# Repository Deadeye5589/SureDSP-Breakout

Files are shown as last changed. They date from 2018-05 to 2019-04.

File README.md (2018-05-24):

# SureDSP-Breakout
Breakout Board for SureDSP to adapt China Modules

This project won't be supportet in any way, but on the other hand it can be used in any way you like.<br>
The creator of this project won't be responsible for any trouble, harm or deadly incidents that should occure while using this project data, parts of the project or complete boards.<br>
Now for the fun part.<br><br>

This breakout board includes an automotive qualified power supply with a quiescent current of >2µA. <br>
The DC/DC converter can supply the DSP down to an input voltage of 6V and is therefore suitable for start/stop systems.<br><br>

The modules can be purchased at the common Chinese webshops like Aliexpress<br><br>

The default configuration can support up to:<br>
4x DAC output via PCM5102 chipset 2,98€ per piece<br>
4x Analog output directly from SureDSP<br>
1x APTx Bluetooth receiver via CSR64215 chipset 8,08€<br>
1x SPDIF input via DIR9001 chipset 11,20€<br>
2x ADC input via PCM1808 Chipsatz 3,12€ per piece<br>
2x Analog Input from SureDSP<br>
1x Debugger 2,92€<br><br>

The PCB is the size of 160x100 mm and a 2 layer design.<br>
Drill holes are 0,8mm or 1,0mm<br>
The PCB can be etched with iron III chloride in a spray booth. <br>
It is possible to manufacture the PCB with tools avaiable to makers.<br>
But don't take on this project if you don't feel like you can do it by your own. <br>
You will not get any support.<br>

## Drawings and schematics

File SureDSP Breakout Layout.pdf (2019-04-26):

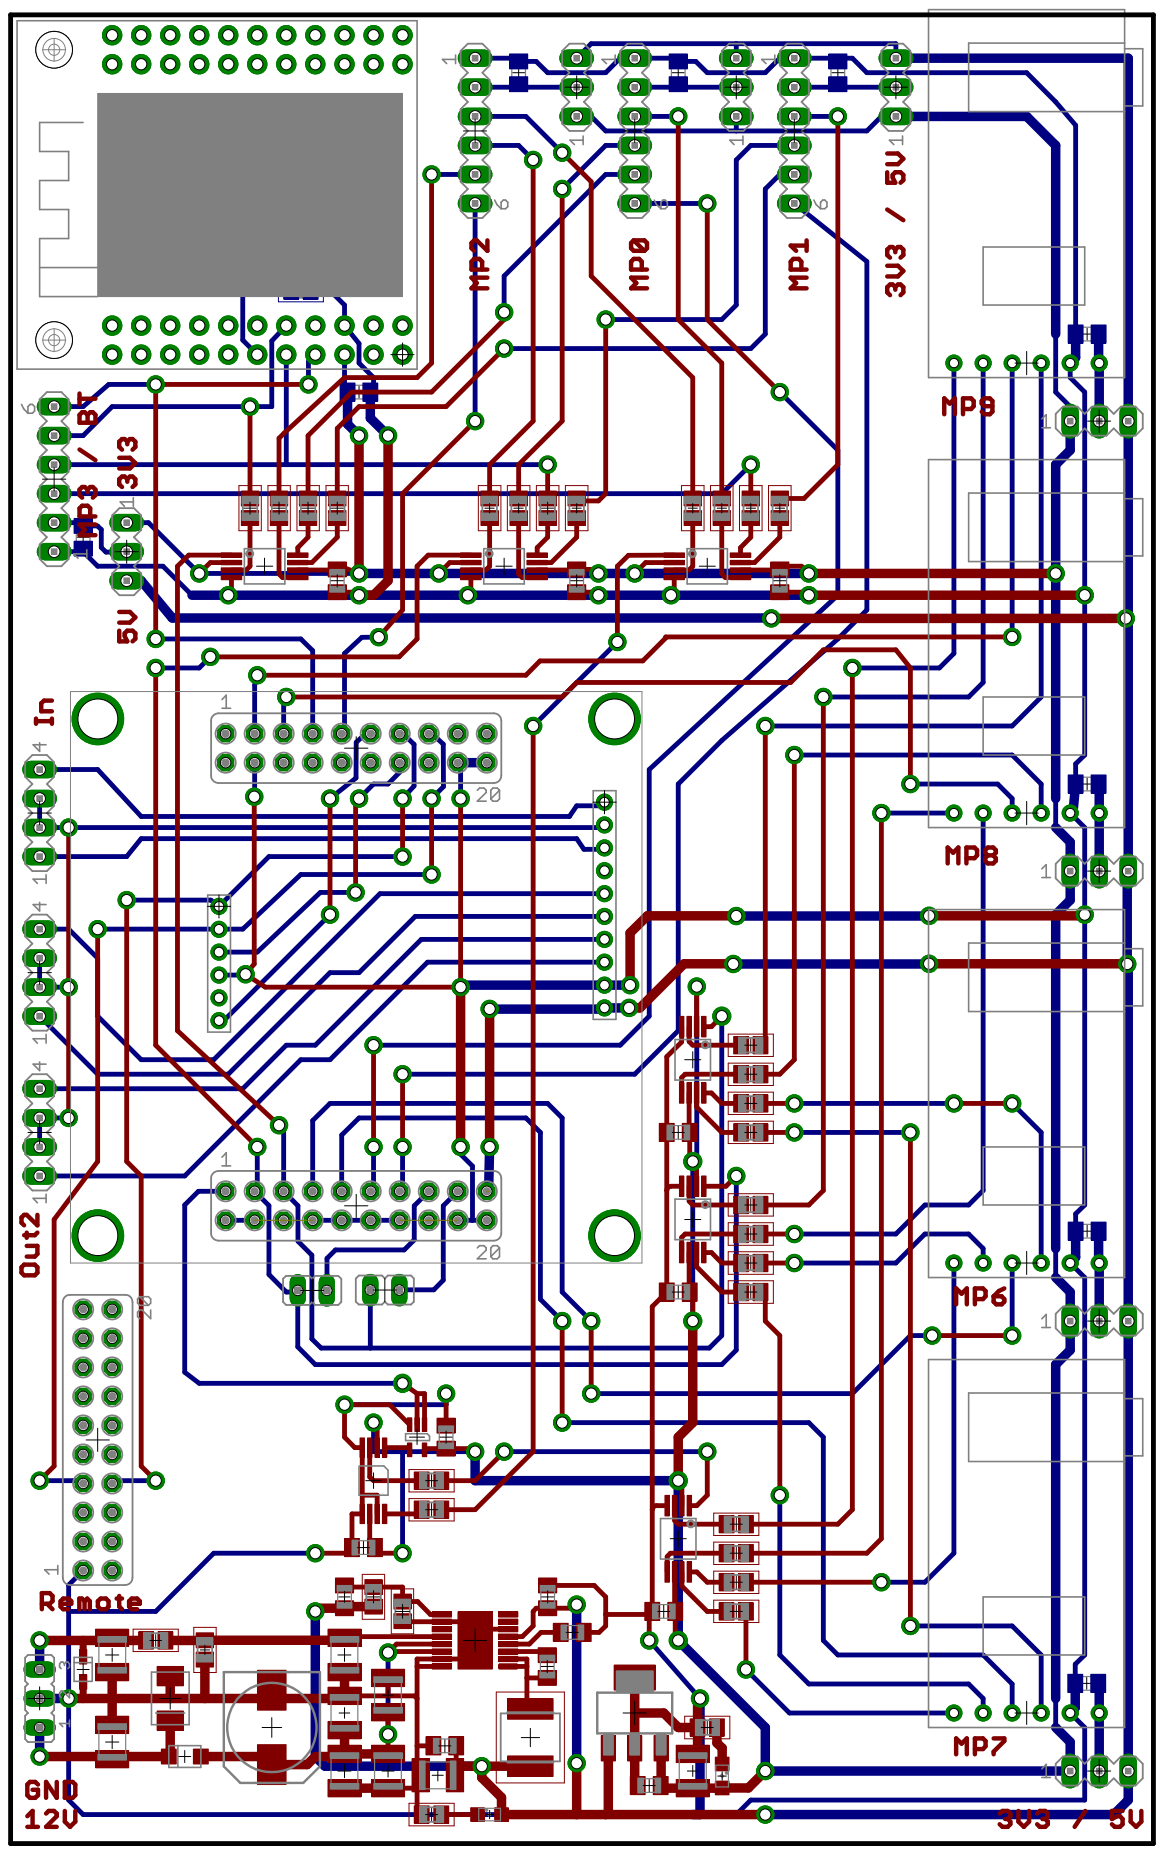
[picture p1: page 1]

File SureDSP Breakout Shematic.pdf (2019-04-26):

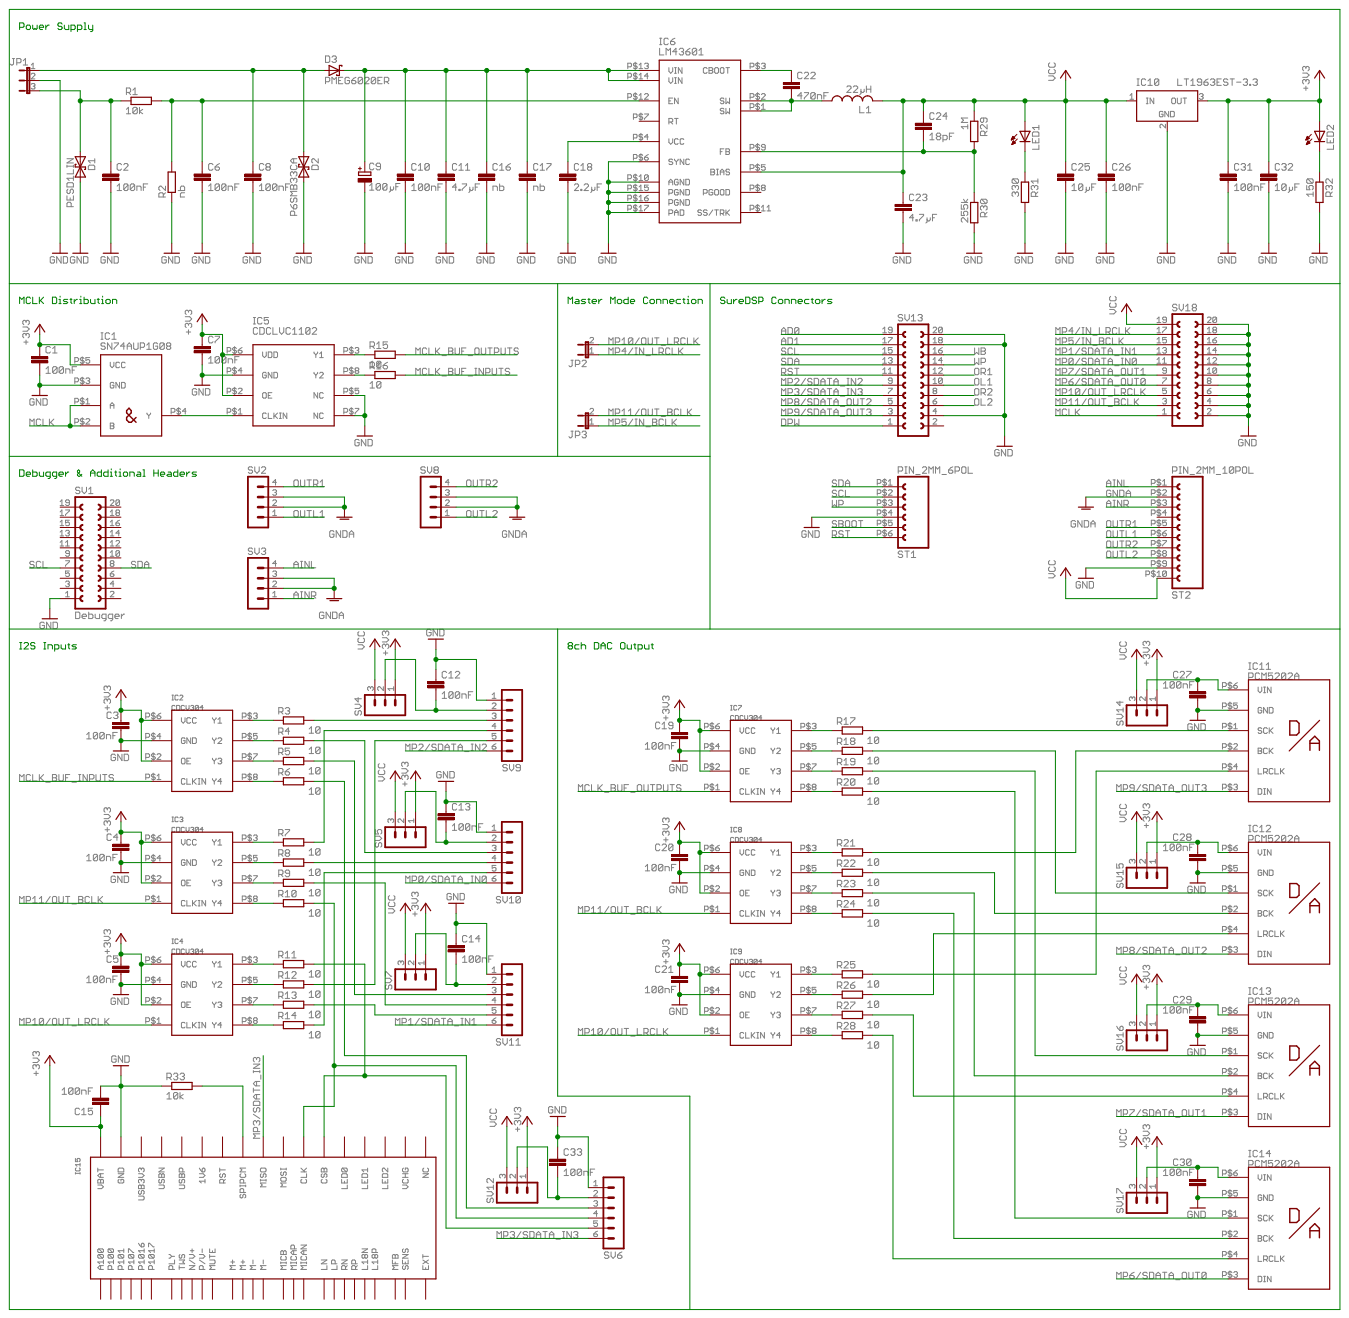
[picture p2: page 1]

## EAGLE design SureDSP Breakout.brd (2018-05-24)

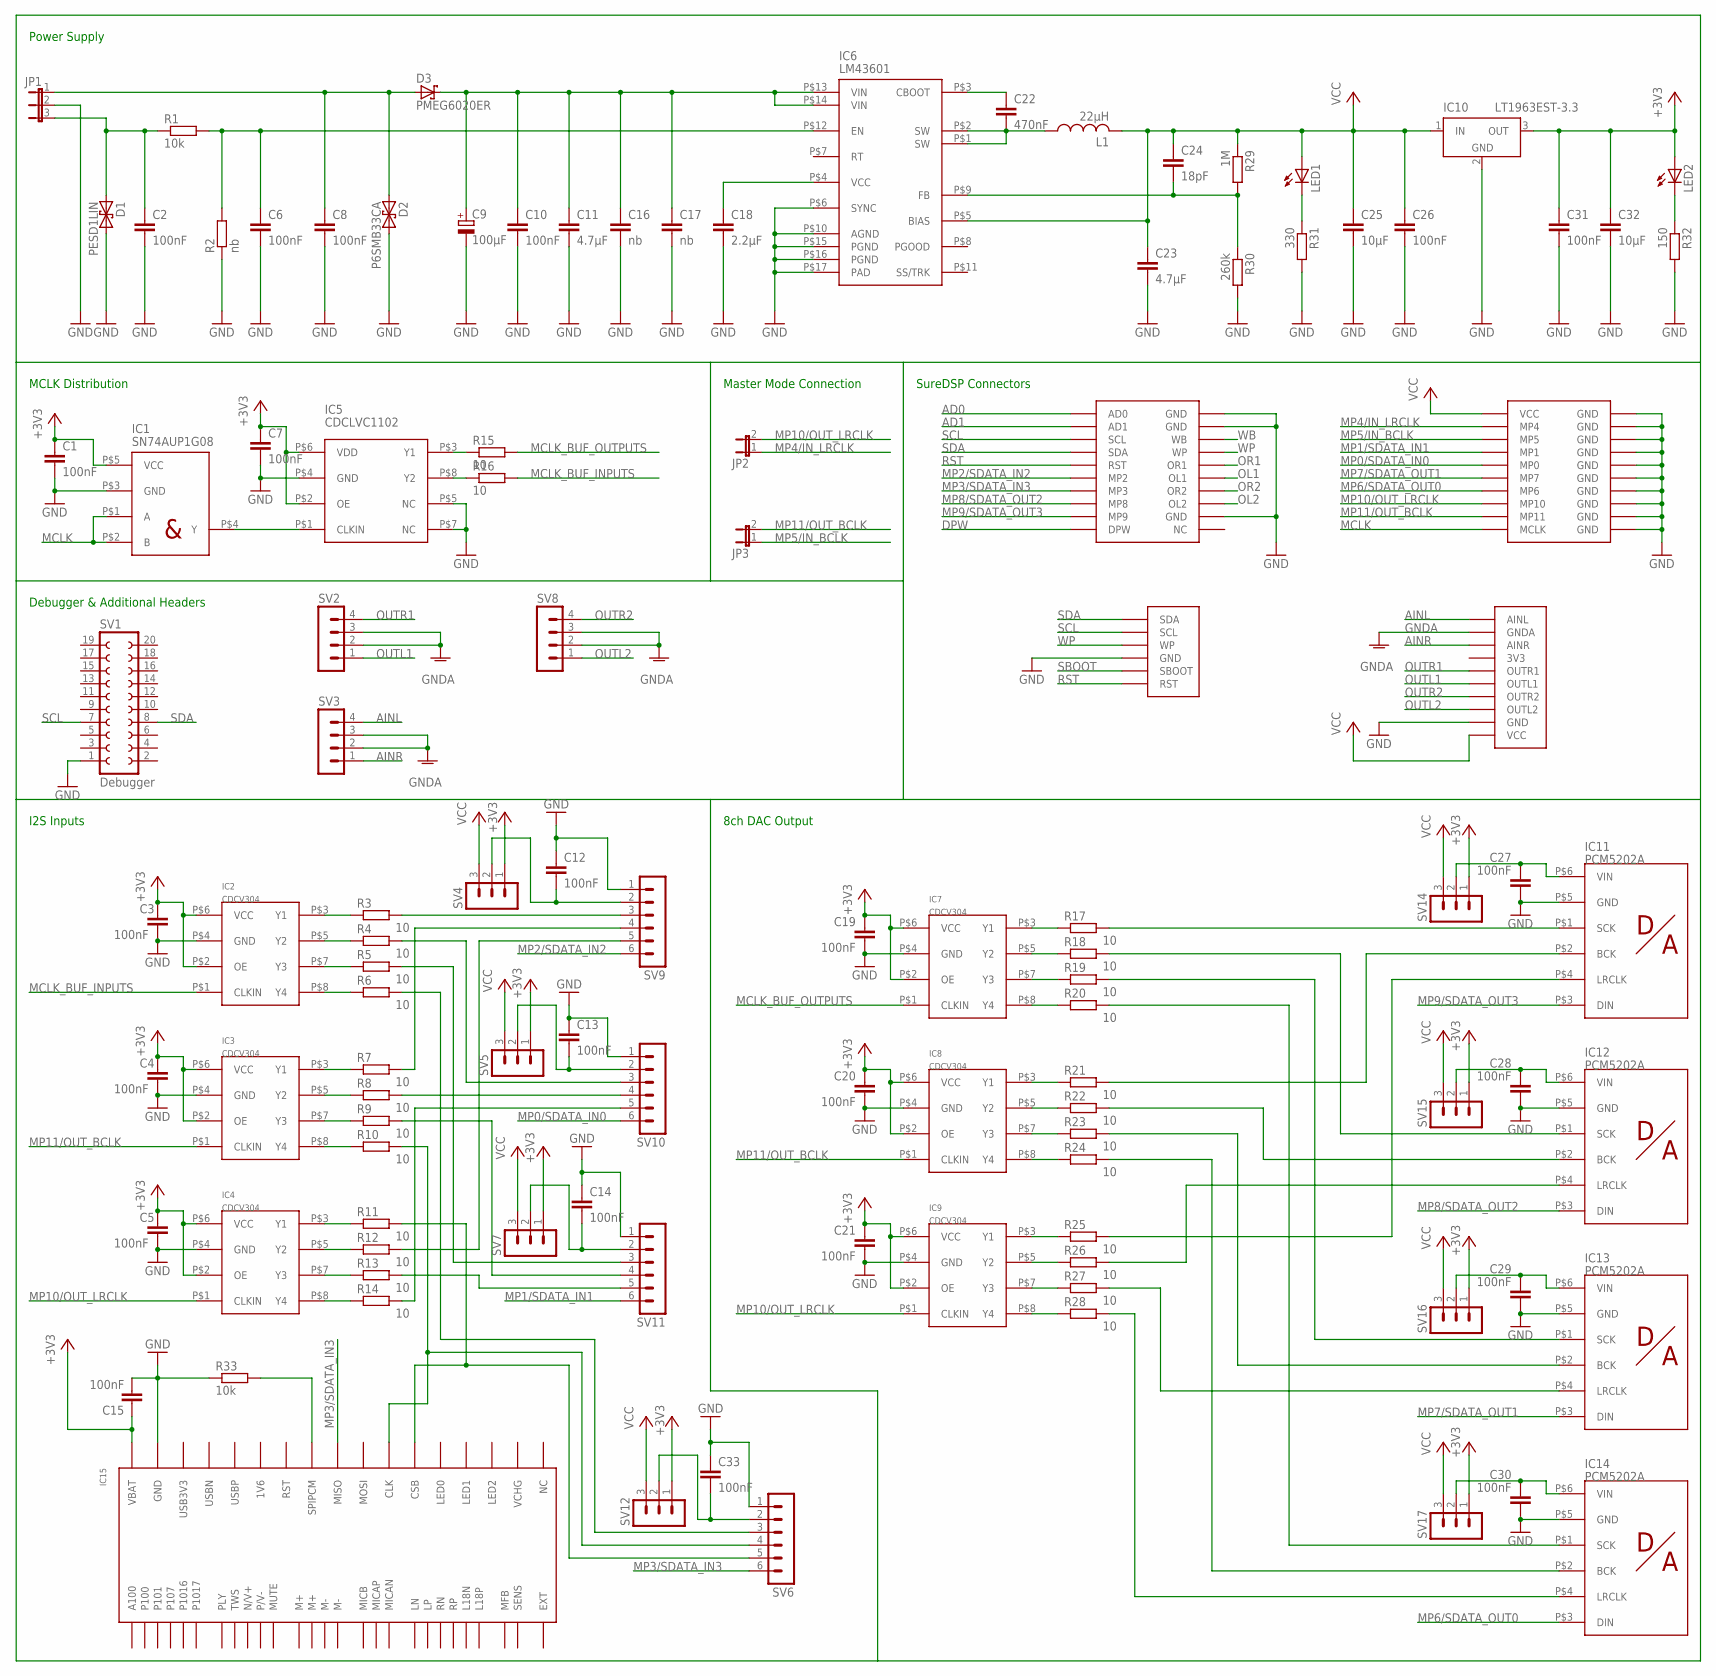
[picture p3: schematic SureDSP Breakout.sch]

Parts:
C1, C3, C4, C5, C7, C12, C13, C14, C15, C19, C20, C21, C26, C27, C28, C29, C30, C31, C33: 100nF; C0805K
C2, C6, C8, C10: 100nF; C1210K
C9: 100µF; 150CLZ-0810
C11: 4.7µF; C1210K
C16, C17: nb; C1210K
C18: 2.2µF; C0805K
C22: 470nF; C0805K
C23: 4.7µF; C0805K
C24: 18pF; C0805K
C25, C32: 10µF; C1210K
D1: PESD1LIN
D2: P6SMB33CA; P6SMB
D3: PMEG6020ER
IC1: SN74AUP1G08
IC2, IC3, IC4, IC7, IC8, IC9: CDCV304
IC5: CDCLVC1102
IC6: LM43601
IC10: LT1963EST-3.3; SOT223
IC11, IC12, IC13, IC14: PCM5202A
IC15: CSRA64215
IC16: SUREDSP
JP1: JP2E; JP2
JP2, JP3: JP1E; JP1
L1: 22µH; L5650M
LED1, LED2: LEDSML0805; SML0805
R1, R33: 10k; R2012
R2: nb; R2012
R3, R4, R5, R6, R7, R8, R9, R10, R11, R12, R13, R14, R15, R16, R17, R18, R19, R20, R21, R22, R23, R24, R25, R26, R27, R28: 10; R2012
R29: 1M; R2012
R30: 260k; R2012
R31: 330; R2012
R32: 150; R2012
SV1: Debugger; FE10-2
SV2, SV3, SV8: MA04-1
SV4, SV5, SV7, SV12, SV14, SV15, SV16, SV17: MA03-1
SV6, SV9, SV10, SV11: MA06-1

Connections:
+3V3: C1.1, C3.1, C4.1, C5.1, C7.1, C15.1, C19.1, C20.1, C21.1, C31.1, C32.1, IC1.P$5 (VCC), IC2.P$2 (OE), IC2.P$6 (VCC), IC3.P$2 (OE), IC3.P$6 (VCC), IC4.P$2 (OE), IC4.P$6 (VCC), IC5.P$2 (OE), IC5.P$6 (VDD), IC7.P$2 (OE), IC7.P$6 (VCC), IC8.P$2 (OE), IC8.P$6 (VCC), IC9.P$2 (OE), IC9.P$6 (VCC), IC10.3 (OUT), IC15.P$5 (VBAT), LED2.A, SV4.1, SV5.1, SV7.1, SV12.1, SV14.1, SV15.1, SV16.1, SV17.1
AD0: IC16.AD0
AD1: IC16.AD1
AINL: IC16.AINL, SV3.4
AINR: IC16.AINR, SV3.1
DPW: IC16.DPW
GND: C1.2, C2.2, C3.2, C4.2, C5.2, C6.2, C7.2, C8.2, C9.-, C10.2, C11.2, C12.1, C13.1, C14.1, C15.2, C16.2, C17.2, C18.2, C19.2, C20.2, C21.2, C23.2, C25.2, C26.2, C27.2, C28.2, C29.2, C30.2, C31.2, C32.2, C33.1, D1.P$2 (2), D2.P$2 (2), IC1.P$3 (GND), IC2.P$4 (GND), IC3.P$4 (GND), IC4.P$4 (GND), IC5.P$4 (GND), IC5.P$5 (NC), IC5.P$7 (NC), IC6.P$6 (SYNC), IC6.P$10 (AGND), IC6.P$15 (PGND), IC6.P$16 (PGND), IC6.P$17 (PAD), IC7.P$4 (GND), IC8.P$4 (GND), IC9.P$4 (GND), IC10.2 (GND), IC10.4 (GND), IC11.P$5 (GND), IC12.P$5 (GND), IC13.P$5 (GND), IC14.P$5 (GND), IC15.P$6 (GND), IC16.GND6ER (GND), IC16.GND10ER (GND), IC16.GND20ER (GND), IC16.GND20ER1 (GND), IC16.GND20ER2 (GND), IC16.P$2 (GND), IC16.P$3 (GND), IC16.P$6 (GND), IC16.P$8 (GND), IC16.P$10 (GND), IC16.P$12 (GND), IC16.P$14 (GND), IC16.P$16 (GND), IC16.P$18 (GND), IC16.P$55 (GND), JP1.2, R2.1, R30.2, R31.2, R32.2, R33.1, SV1.1, SV6.1, SV9.1, SV10.1, SV11.1
GNDA: IC16.AGND (GNDA), SV2.2, SV2.3, SV3.2, SV3.3, SV8.2, SV8.3
MCLK: IC1.P$1 (A), IC1.P$2 (B), IC16.MCLK
MCLK_BUF_INPUTS: IC2.P$1 (CLKIN), R16.2
MCLK_BUF_OUTPUTS: IC7.P$1 (CLKIN), R15.2
MP0/SDATA_IN0: IC16.MP0, SV10.6
MP1/SDATA_IN1: IC16.MP1, SV11.6
MP2/SDATA_IN2: IC16.MP2, SV9.6
MP3/SDATA_IN3: IC15.P$7 (MISO), IC16.MP3, SV6.6
MP4/IN_LRCLK: IC16.MP4, JP2.1
MP5/IN_BCLK: IC16.MP5, JP3.1
MP6/SDATA_OUT0: IC14.P$3 (DIN), IC16.MP6
MP7/SDATA_OUT1: IC13.P$3 (DIN), IC16.MP7
MP8/SDATA_OUT2: IC12.P$3 (DIN), IC16.MP8
MP9/SDATA_OUT3: IC11.P$3 (DIN), IC16.MP9
MP10/OUT_LRCLK: IC4.P$1 (CLKIN), IC9.P$1 (CLKIN), IC16.MP10, JP2.2
MP11/OUT_BCLK: IC3.P$1 (CLKIN), IC8.P$1 (CLKIN), IC16.MP11, JP3.2
unnamed: IC7.P$3 (Y1), R17.1
unnamed: IC12.P$1 (SCK), R18.2
unnamed: IC13.P$1 (SCK), R19.2
unnamed: IC14.P$1 (SCK), R20.2
unnamed: IC14.P$2 (BCK), R24.2
unnamed: IC14.P$4 (LRCLK), R28.2
unnamed: IC13.P$4 (LRCLK), R27.2
unnamed: IC13.P$2 (BCK), R23.2
unnamed: IC12.P$4 (LRCLK), R26.2
unnamed: IC12.P$2 (BCK), R22.2
unnamed: IC11.P$4 (LRCLK), R25.2
unnamed: IC11.P$2 (BCK), R21.2
unnamed: IC7.P$5 (Y2), R18.1
unnamed: IC7.P$7 (Y3), R19.1
unnamed: IC7.P$8 (Y4), R20.1
unnamed: IC8.P$3 (Y1), R21.1
unnamed: IC8.P$5 (Y2), R22.1
unnamed: IC8.P$7 (Y3), R23.1
unnamed: IC8.P$8 (Y4), R24.1
unnamed: IC9.P$3 (Y1), R25.1
unnamed: IC9.P$5 (Y2), R26.1
unnamed: IC9.P$7 (Y3), R27.1
unnamed: IC9.P$8 (Y4), R28.1
unnamed: IC11.P$1 (SCK), R17.2
unnamed: R3.2, SV9.3
unnamed: IC1.P$4 (Y), IC5.P$1 (CLKIN)
unnamed: IC5.P$3 (Y1), R15.1
unnamed: IC5.P$8 (Y2), R16.1
unnamed: R7.2, SV9.4
unnamed: R12.2, SV9.5
unnamed: R4.2, SV10.3
unnamed: R5.2, SV11.3
unnamed: C12.2, SV4.2, SV9.2
unnamed: R8.2, SV10.4
unnamed: R9.2, SV11.4
unnamed: C14.2, SV7.2, SV11.2
unnamed: R14.2, SV10.5
unnamed: R13.2, SV11.5
unnamed: IC2.P$3 (Y1), R3.1
unnamed: IC2.P$5 (Y2), R4.1
unnamed: IC2.P$7 (Y3), R5.1
unnamed: IC2.P$8 (Y4), R6.1
unnamed: IC3.P$3 (Y1), R7.1
unnamed: IC3.P$5 (Y2), R8.1
unnamed: IC3.P$7 (Y3), R9.1
unnamed: IC3.P$8 (Y4), R10.1
unnamed: IC4.P$3 (Y1), R11.1
unnamed: IC4.P$5 (Y2), R12.1
unnamed: IC4.P$7 (Y3), R13.1
unnamed: IC4.P$8 (Y4), R14.1
unnamed: C33.2, SV6.2, SV12.2
unnamed: C18.1, IC6.P$4 (VCC)
unnamed: C9.+, C10.1, C11.1, C16.1, C17.1, D3.P$2 (C), IC6.P$13 (VIN), IC6.P$14 (VIN)
unnamed: C22.2, IC6.P$1 (SW), IC6.P$2 (SW), L1.1
unnamed: C22.1, IC6.P$3 (CBOOT)
unnamed: C2.1, D1.P$1 (1), JP1.3, R1.1
unnamed: C8.1, D2.P$1 (1), D3.P$1 (A), JP1.1
unnamed: C24.2, IC6.P$9 (FB), R29.2, R30.1
unnamed: C6.1, IC6.P$12 (EN), R1.2, R2.2
unnamed: C30.1, IC14.P$6 (VIN), SV17.2
unnamed: C29.1, IC13.P$6 (VIN), SV16.2
unnamed: C28.1, IC12.P$6 (VIN), SV15.2
unnamed: C27.1, IC11.P$6 (VIN), SV14.2
unnamed: C13.2, SV5.2, SV10.2
unnamed: IC15.P$11 (SPIPCM), R33.2
unnamed: LED2.C, R32.1
unnamed: LED1.C, R31.1
unnamed: R6.2, SV6.3
unnamed: IC15.P$9 (CLK), R10.2, SV6.4
unnamed: IC15.P$10 (CSB), R11.2, SV6.5
OL1: IC16.OL1
OL2: IC16.OL2
OR1: IC16.OR1
OR2: IC16.OR2
OUTL1: IC16.OUTL1, SV2.1
OUTL2: IC16.OUTL2, SV8.1
OUTR1: IC16.OUTR1, SV2.4
OUTR2: IC16.OUTR2, SV8.4
RST: IC16.RESET (RST), IC16.RST
SBOOT: IC16.SBOOT
SCL: IC16.SCL, IC16.SCL20ER (SCL), SV1.7
SDA: IC16.SDA, IC16.SDA20ER (SDA), SV1.8
VCC: C23.1, C24.1, C25.1, C26.1, IC6.P$5 (BIAS), IC10.1 (IN), IC16.VIN10ER (VCC), IC16.VIN@2 (VCC), L1.2, LED1.A, R29.1, SV4.3, SV5.3, SV7.3, SV12.3, SV14.3, SV15.3, SV16.3, SV17.3
WB: IC16.WB
WP: IC16.WP, IC16.WP20ER (WP)

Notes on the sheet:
SureDSP Connectors
8ch DAC Output
Master Mode Connection
MCLK Distribution
Debugger & Additional Headers
I2S Inputs
Power Supply

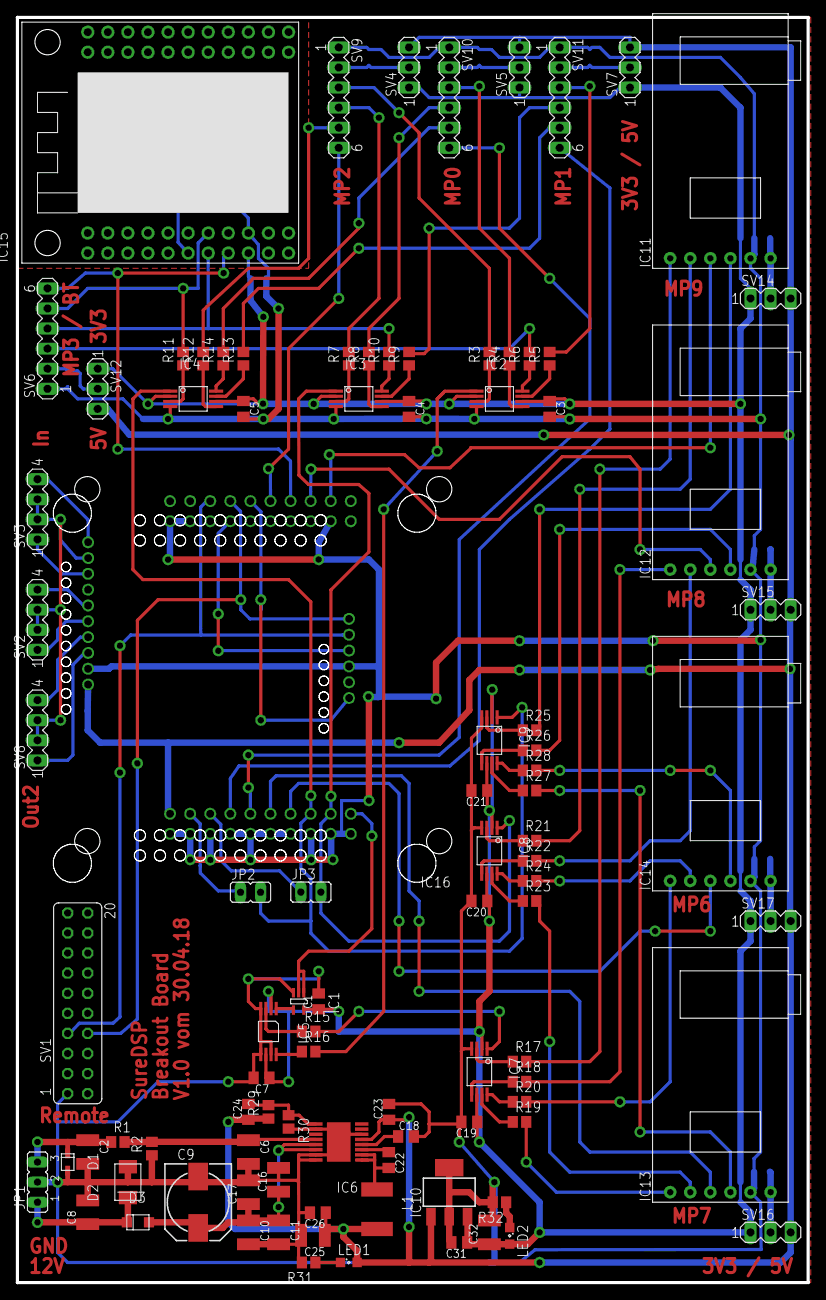
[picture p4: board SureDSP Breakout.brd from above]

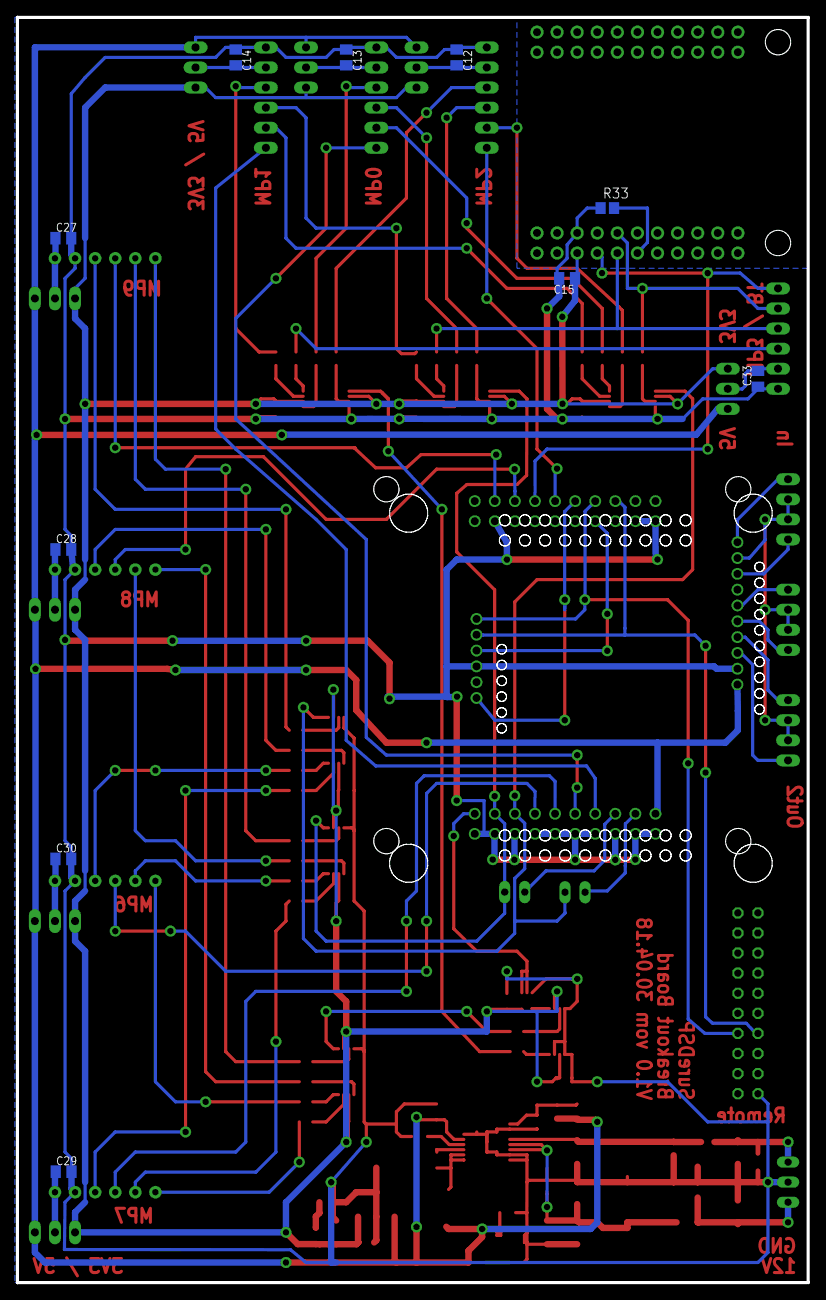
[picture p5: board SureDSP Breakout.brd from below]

Board: 2 copper layers, 100.0 x 160.0 mm, 107 parts (10 on the bottom side), 99 nets.
